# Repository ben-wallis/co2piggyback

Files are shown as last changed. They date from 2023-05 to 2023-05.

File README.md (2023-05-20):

## Introduction
This repository contains guides on modifying off-the-shelf NDIR CO2 sensors to report their data to home automation systems such as Home Assistant via the [ESPHome](https://esphome.io/) firmware flashed to a [WEMOS D1 mini](https://www.wemos.cc/en/latest/d1/d1_mini.html) ESP8266 microcontroller. 

These inexpensive (around £4) tiny microcontroller boards have built-in WiFi, and can be powered by either 3.3V or 5V - perfect for sneaking inside an existing device to give it new capabilities.

The projects in this repository rely on "piggybacking" the existing CO2 sensor installed in devices by passively listening to the data sent over the UART TX line, allowing the host device to function as designed.

For sensors that use UART, this means identifying the TX pin, a source of power (usually the 5V and GND pins of the CO2 sensor can be used), and the UART communication protocol.

## Devices 
|Device|Sensors|
|-|-|
|[SA1200P](./sa1200p/README.md)|CO2, Temperature, Relative Humidity|

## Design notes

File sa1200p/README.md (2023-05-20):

# Riiai SA1200P CO2 Monitor

This CO2 monitor was purchased from Amazon UK for £33.29 - it can also be found on AliExpress under various other brand names for wildly differing prices.

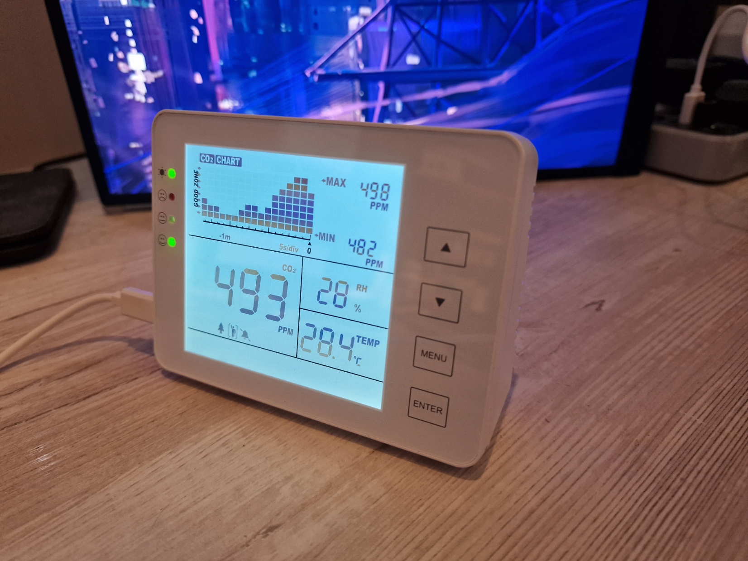
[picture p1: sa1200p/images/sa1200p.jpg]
SA1200P CO2 monitor


The CO2 sensor inside is a [Cubic CM1106-C](https://en.gassensor.com.cn/CO2Sensor/info_itemid_86.html) [ [Datasheet](https://en.gassensor.com.cn/Product_files/Specifications/CM1106-C%20Single%20Beam%20NDIR%20CO2%20Sensor%20Module%20Specification.pdf) ] which has similar dimensions to other CO2 sensors, and an identical pinout to the MTP40-F CO2 sensor but with a different data protocol.

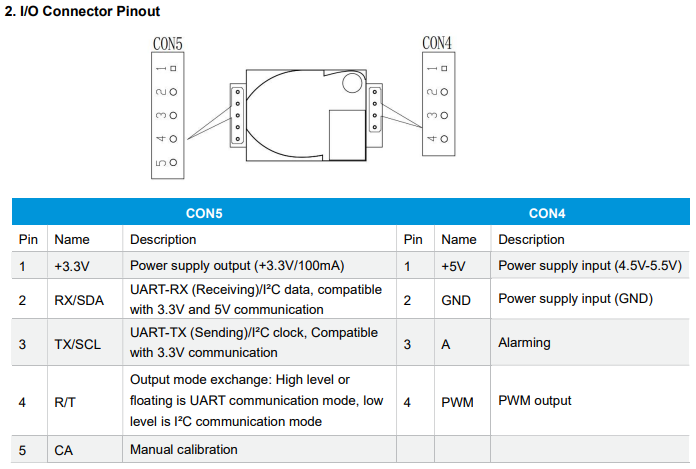
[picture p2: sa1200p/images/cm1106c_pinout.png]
Cubic CM1106-C Pinout


For the purpose of this project, we're only interested in the +5V, GND and TX pins. The RX pin is shown connected to the D1 Mini in later photos, _this is not required_.

## Connecting the D1 Mini to the CO2 Sensor

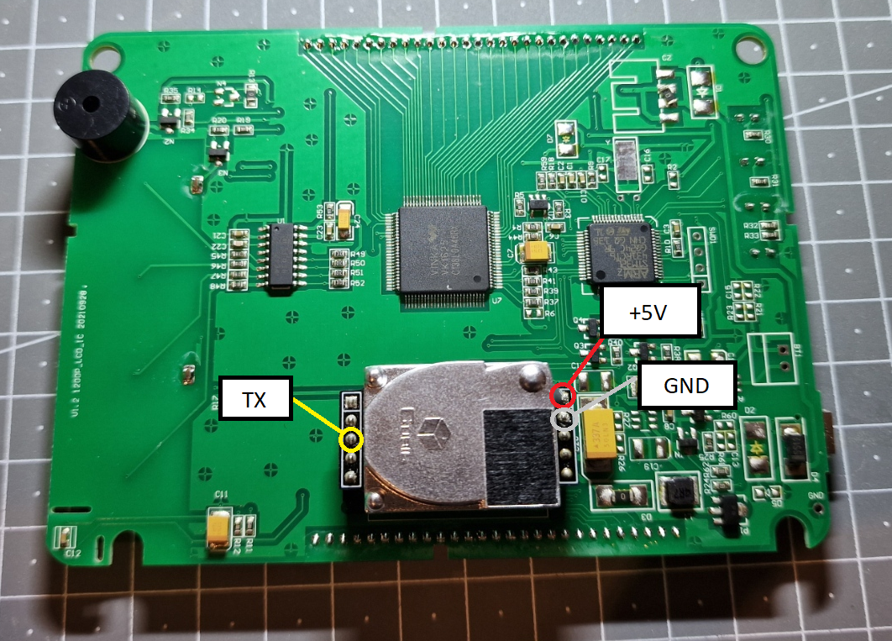
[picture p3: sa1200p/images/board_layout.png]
SA1200P CO2 Monitor circuit board


The inside of the case is pretty spacious - there's enough room to mount the D1 mini directly to the case. STL and STEP files are included for the 3D printed mount - when printing, supports are required, and due to how narrow it is the channel that holds the circuit board will likely need cutting/dremelling out if you don't have the ability to print dissolvable supports. The mount can then be attached to the case with your adhesive of choice (hot glue etc).

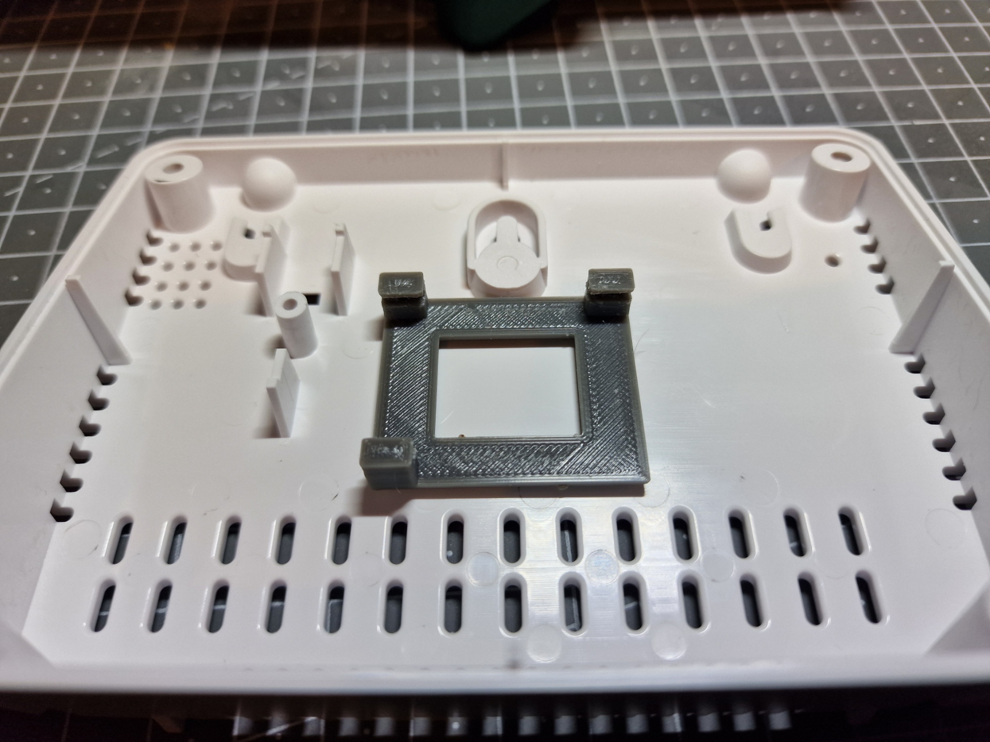
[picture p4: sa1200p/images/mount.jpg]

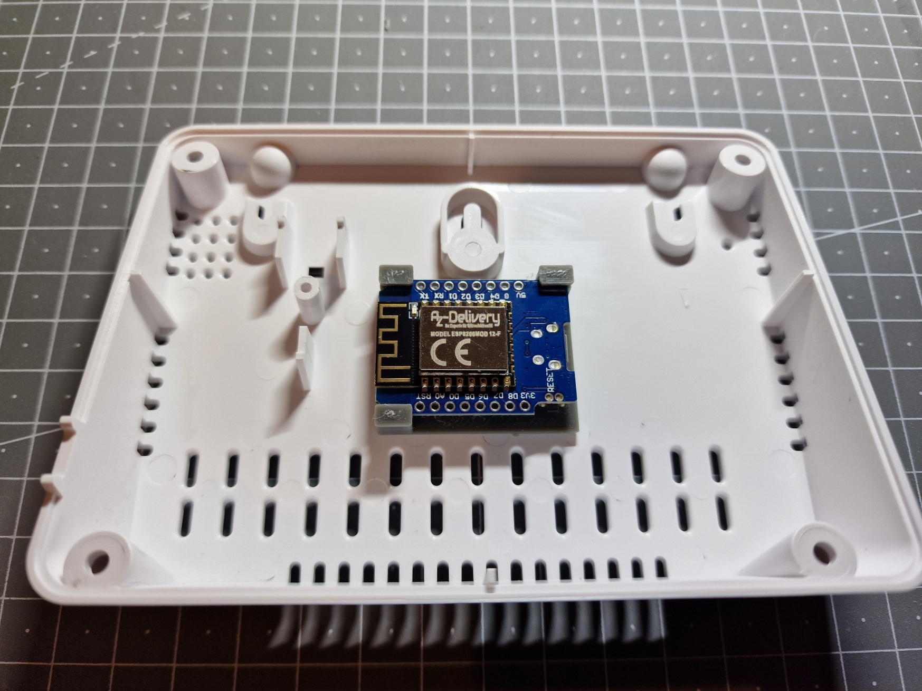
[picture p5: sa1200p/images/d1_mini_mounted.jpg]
Rear case with D1 Mini mounted


Wiring the D1 mini to the CO2 sensor simply requires connecting 5V to 5V, GND to GND, and TX on the sensor to the GPIO pin of your choice which will be configured as UART RX in the ESPHome config. As mentioned above the sensor's RX line is connected in this photo but this is not necessary.

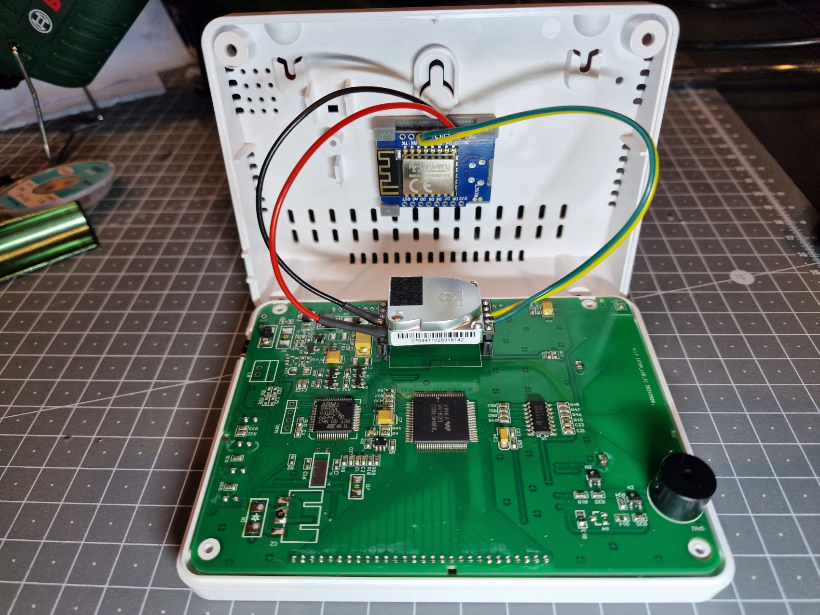
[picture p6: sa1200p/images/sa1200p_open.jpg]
SA1200P CO2 Monitor with D1 Mini mounted


## ESPHome Firmware Installation

These instructions are for Home Assistant but are likely similar for other ESPHome platforms.

Copy the `esphome-web-sa1200p.yaml`, `secrets.yaml` (optional if you already have a secrets file) and `cubic_cm1106c_passive_sensor.h` files to the `esphome` directory in Home Assistant.

The SA1200P device polls the CO2 sensor for its PPM reading every 5 seconds, so this is the fastest update rate we can achieve since this is a passive setup where we rely on the existing hardware to drive the CO2 sensor. The firmware is configured to report an update to ESPHome every 60 seconds by default (i.e only using every 12th update), this can be configured by changing the `TARGET_UPDATE_SECS` value in `cubic_cm1106c_passive_sensor.h`.

The `esphome-web-sa1200p.yaml` file needs customising to specify your desired sensor name, as well as setting the UART RX/TX pins if you don't want to use pin D1 (GPIO5) as the UART RX.

Once flashed to the D1 mini, if everything is wired correctly you should start seeing CO2 readings logged by the D1 mini. The D1 mini will receive sensor values around 5 seconds before the display updates, as the device appears to internally buffer values for a period before displaying them.

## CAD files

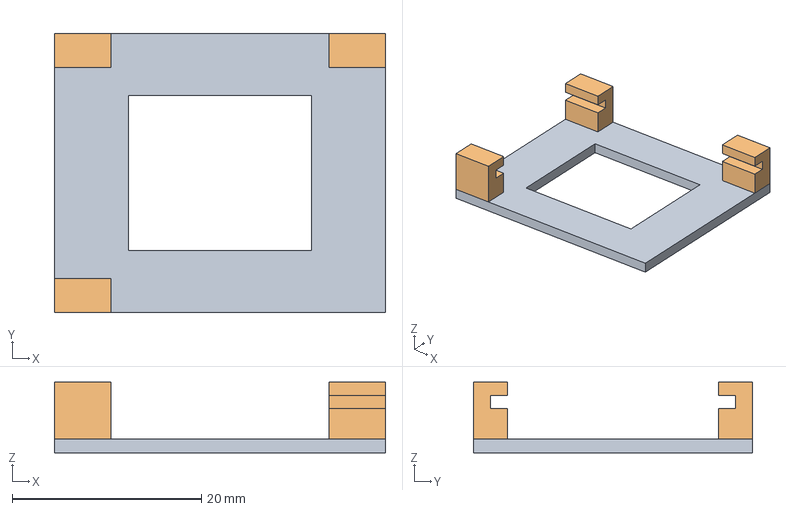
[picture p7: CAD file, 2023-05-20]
sa1200p/d1_mini_mount.step
35.0 x 29.5 x 7.50 mm

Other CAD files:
sa1200p/d1_mini_mount.stl

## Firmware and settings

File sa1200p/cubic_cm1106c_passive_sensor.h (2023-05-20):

class CM1106CPassiveSensor : public Component, public Sensor, public UARTDevice {
    public:
    CM1106CPassiveSensor(UARTComponent *parent) : UARTDevice(parent) {}

    float get_setup_priority() const override { return esphome::setup_priority::DATA; }

    // CM11060-C Datasheet: https://en.gassensor.com.cn/Product_files/Specifications/CM1106-C%20Single%20Beam%20NDIR%20CO2%20Sensor%20Module%20Specification.pdf

    enum: unsigned int {
        PREHEATING = 1U,
        SENSOR_ERROR = 2U, 
        OVER_RANGE = 4U,
        UNDER_RANGE = 8U,
        NON_CALIBRATED = 16U,
        LIGHT_AGING = 32U,
        DRIFT = 64U,
        RESERVED = 128U,
    };

    // The number of seconds that the device sends out a ppm reading
    const int DEVICE_UPDATE_SECS = 5;

    // The desired update frequency emitted to ESPHome
    const int TARGET_UPDATE_SECS = 60;
    
    const int UPDATE_DIVISOR = TARGET_UPDATE_SECS / DEVICE_UPDATE_SECS;

    // Initialise the count so that a reading is taken on the first loop after boot
    int count = UPDATE_DIVISOR - 1;

    void loop() override {
        while (available()) {
            // Wait for the 0x16 0x05 0x01 preamble indicating a CO2 reading response
            if(read() == 0x16 && read() == 0x05 && read() == 0x01) {
                int df1 = read();
                int df2 = read();
                int df3 = read();
                
                int ppm = df1 * 256 + df2;

                bool preheating = (df3 & PREHEATING);
                bool sensor_error = (df3 & SENSOR_ERROR) > 0;
                bool over_range = (df3 & OVER_RANGE) > 0;
                bool under_range = (df3 & UNDER_RANGE) > 0;
                bool non_calibrated = (df3 & NON_CALIBRATED) > 0;
                bool light_aging = (df3 & LIGHT_AGING) > 0;
                bool drift = (df3 & drift) > 0;

                // TODO: Log these error states

                // Only publish updates every TARGET_UPDATE_SECS
                if (count++ % UPDATE_DIVISOR == 0) {
                    publish_state(ppm);
                }                
            }
        }   
    }
};
